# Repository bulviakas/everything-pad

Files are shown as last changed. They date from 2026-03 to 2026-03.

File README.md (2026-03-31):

# Everything pad - Custom macropad
A macropad project for the __Blueprint program__ by [Hack Club](https://hackclub.com/). 

The mini-keyboard features: 
  * 6 programmable keys
  * Rotary encoder
  * 8 RGB LEDs for backlight
  * OLED display

Designed to be a helpful tool while editing, gaming or just deep in flow state. ***The main goal - versatility***: multiple modes for every needed occasion (system sound control, application shortcuts, backlight configuration).

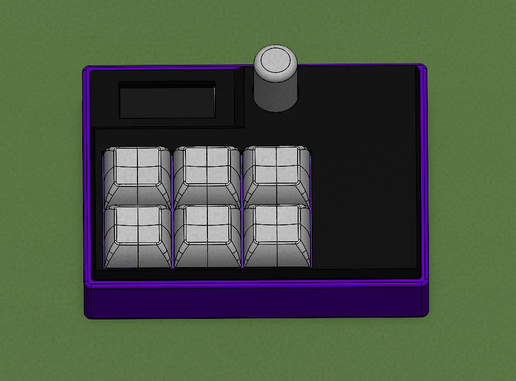
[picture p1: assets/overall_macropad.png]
Latest full version of the Everything pad


### Tools

* **PCB**: Custom-designed using **KiCad**
* **Case**: Modeled in **SolidWorks**
* **Firmware**: Built with **QMK**, supporting multiple layers, RGB lighting, encoder input, and OLED display

### Status
(2026-03-31) Project still in progress - no physical testing yet!

## PCB
### Schematic view

The keys and the rotary encoder are connected in a matrix.

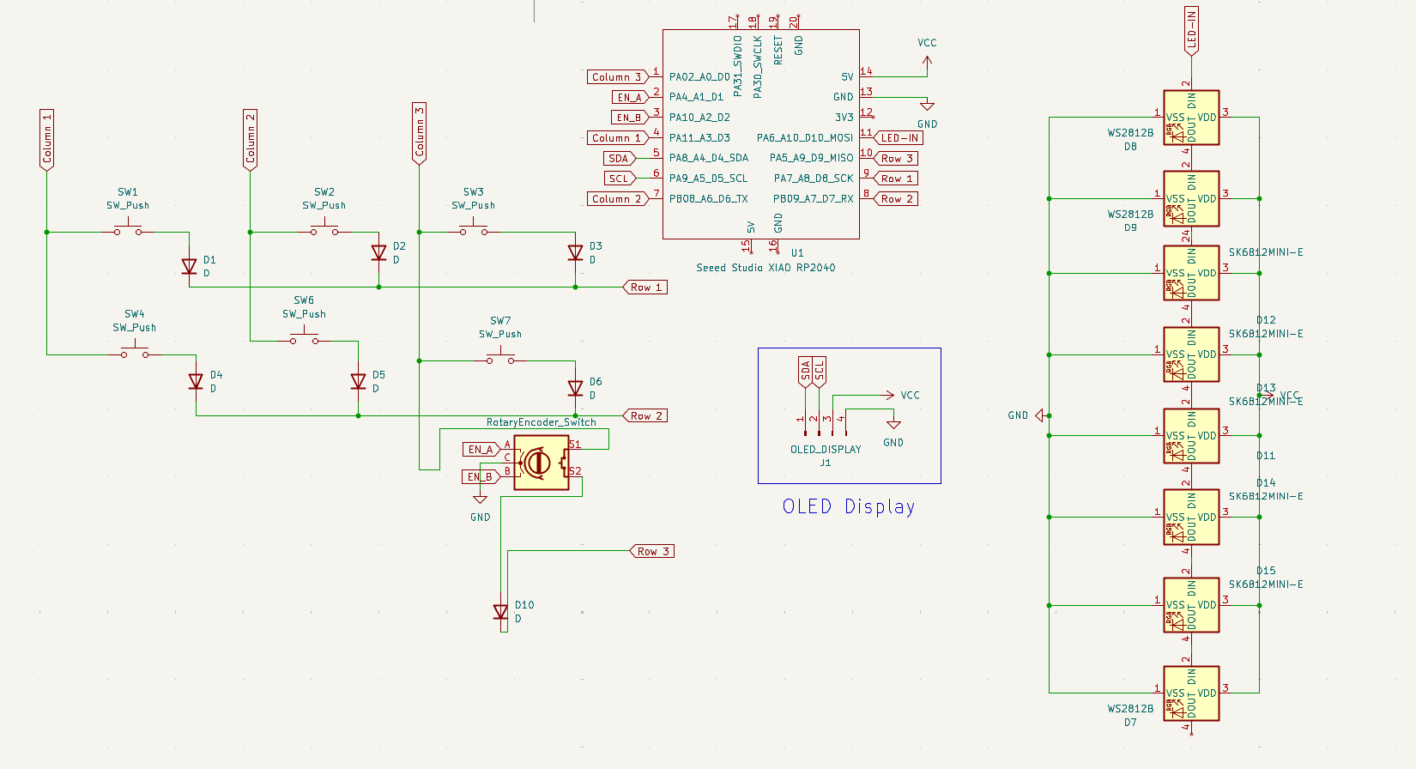
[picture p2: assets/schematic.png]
Scematic view of the Everything Pad


### The product itself

A personal character Steve was made with **Inkscape**. Everyting is connected over 2 layers, with 0.4mm traces and GND fields. SK6812-MINI-E LED footprints were modified due to clearance errors.

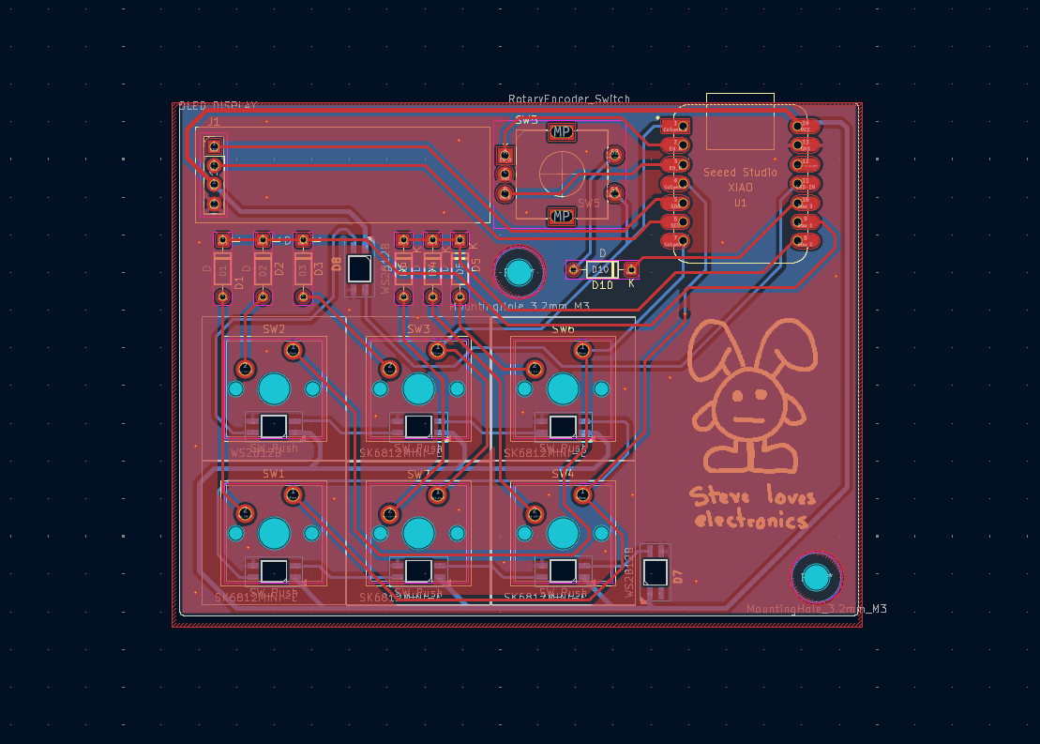
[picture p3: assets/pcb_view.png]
PCB view of the project


## CAD model

The assembly process is quite simple - the PCB is mounted onto the bottom part of the case with 2 M3 bolts and heatset inserts. Top cover just slides in from the top.

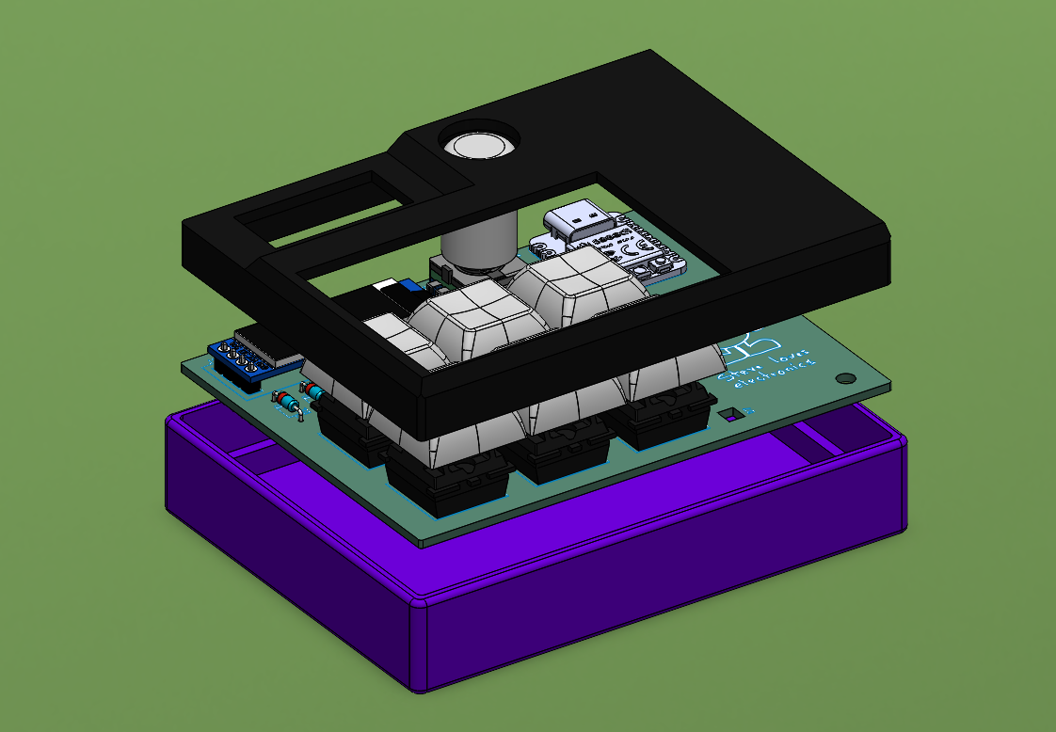
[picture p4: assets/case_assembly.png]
Assembly view of the case


## Firmware

As of now, the code is purely theoretical, since there is no way to test it. However, _in theory_, the keyboard has 3 modes:
* **System sound control** - play/pause music, increase/decrease volume, mute, etc.
* **Application shortcuts** - case-specific keybinds, eg. Discord toggle mute, toggle camera
* **RBG backlight configuration** - increase/decrease brightness, hue, etc.

The colour of the RBG backlight shows the currently active mode (SSC - Blue, Apps - Green, etc.). OLED display serves as the main info output when switching modes. Since the macropad cannot read real system sound values, it stores simulated volume and displays a simple bar on-screen when relevant.

## BOM
 A list of everything used to make this masterpiece:
 * 1x Seeed XIAO RP2040
 * 7x through-hole 1N4148 Diodes
 * 6x MX-Style switches
 * 1x EC11 Rotary encoder
 * 1x 0.91 inch OLED display (GND-VCC-SCL-SDA)
 * 6x white blank DSA keycaps
 * 8x SK6812 MINI-E LEDs
 * 2x M3x16mm screws
 * 2x M3x5mx4mm heatset inserts
 * 1x case (2 printed parts)
 * 1x printed knob for the encoder
 * Some joy and whimsy~

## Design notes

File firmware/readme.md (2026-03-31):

# everything_pad

*A short description of the keyboard/project*

* Keyboard Maintainer: [Akvilė Mačiulytė](https://github.com/bulviakas)
* Hardware Supported: Seeed XIAO RP2040
* Hardware Availability: -

Make example for this keyboard (after setting up your build environment):

    make everything_pad:default

Flashing example for this keyboard:

    make everything_pad:default:flash

See the [build environment setup](https://docs.qmk.fm/#/getting_started_build_tools) and the [make instructions](https://docs.qmk.fm/#/getting_started_make_guide) for more information. Brand new to QMK? Start with our [Complete Newbs Guide](https://docs.qmk.fm/#/newbs).

## Bootloader

Enter the bootloader in 3 ways:

* **Bootmagic reset**: Hold down the key at (0,0) in the matrix (usually the top left key or Escape) and plug in the keyboard
* **Physical reset button**: Briefly press the button on the back of the PCB - some may have pads you must short instead
* **Keycode in layout**: Press the key mapped to `QK_BOOT` if it is available

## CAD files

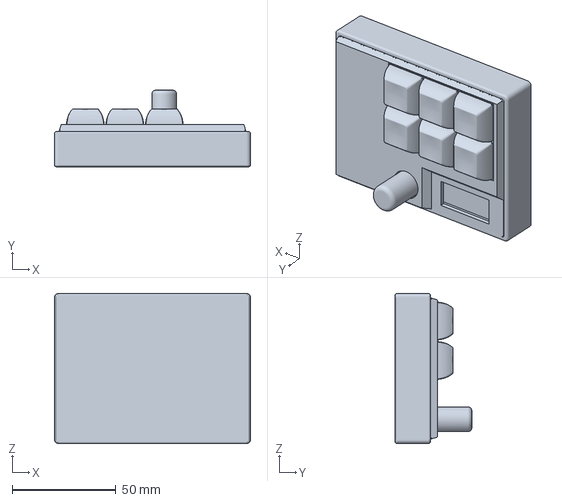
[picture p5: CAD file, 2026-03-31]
cad/everything_pad_assembly.3MF
94.5 x 37.0 x 72.5 mm

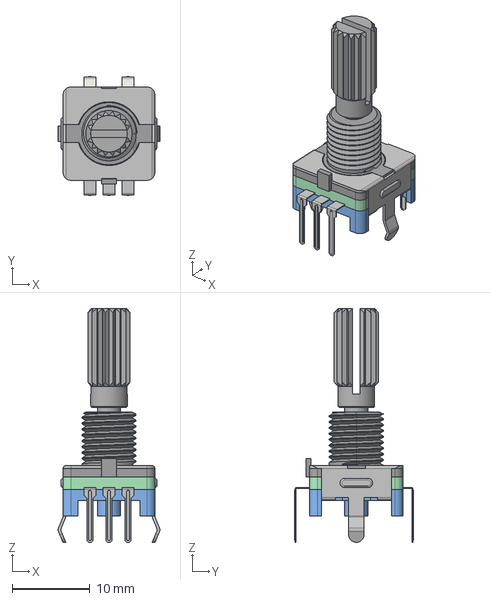
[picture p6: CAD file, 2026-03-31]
pcb/3d-models/EC11_Rotary_Encoder_Switched.step
13.1 x 15.3 x 30.1 mm

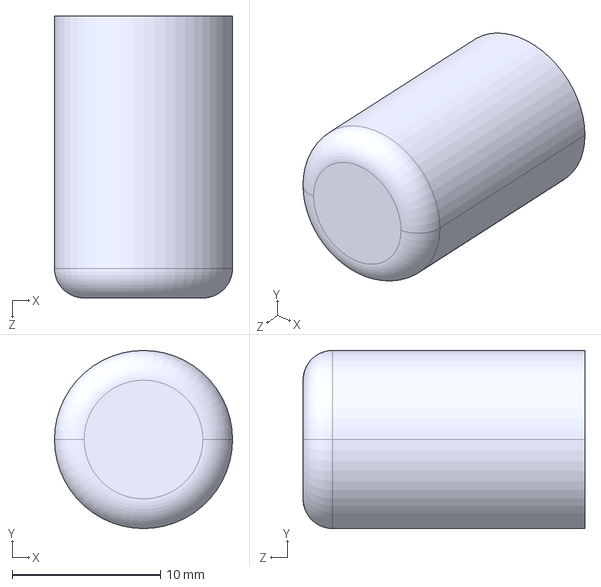
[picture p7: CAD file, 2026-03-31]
production/knob.STEP
12.0 x 12.0 x 19.0 mm

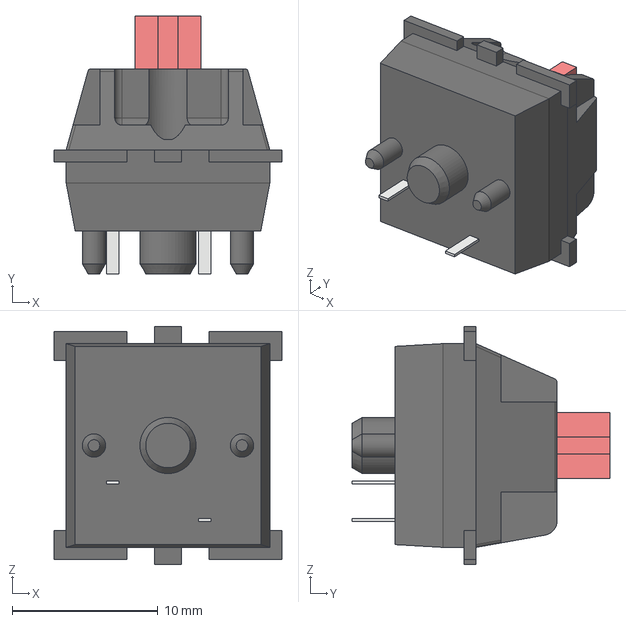
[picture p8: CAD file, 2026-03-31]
pcb/3d-models/switch.step
15.6 x 17.7 x 16.3 mm

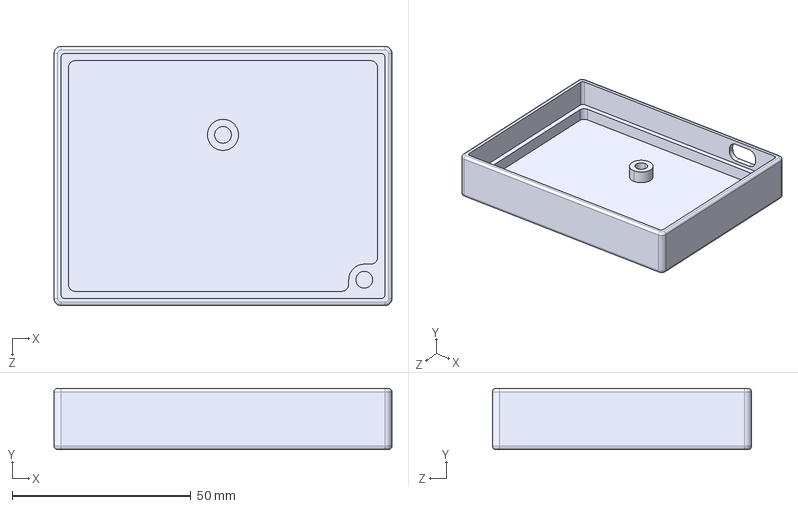
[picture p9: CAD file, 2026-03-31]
production/bottom.STEP
94.5 x 17.1 x 72.5 mm

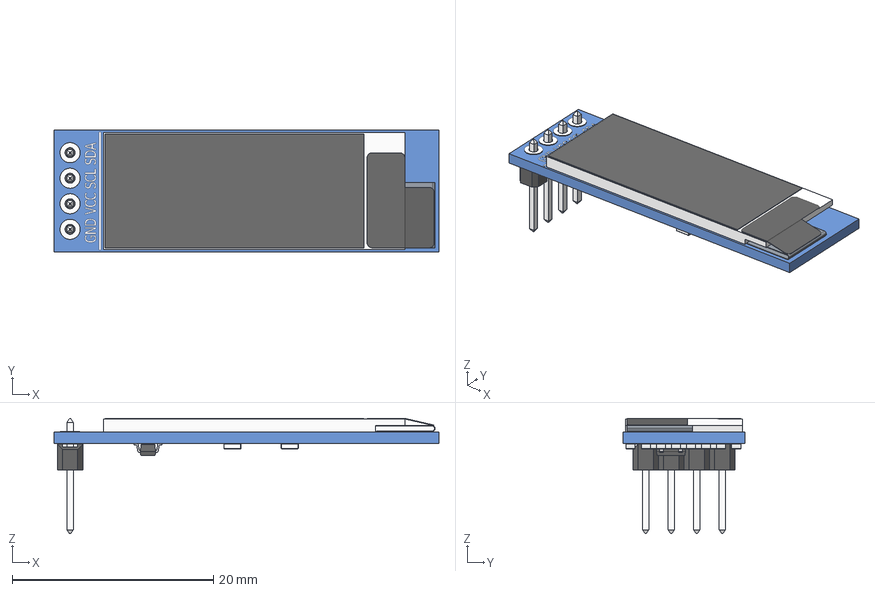
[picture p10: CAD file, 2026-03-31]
pcb/3d-models/OLED_0.91_128x32.stp
38.3 x 12.1 x 11.5 mm
OLED_0.91_128x32
Pin Header 4 x 1 TH 2.54mm Pitch
RESC-0603 x 13
2SD0601A

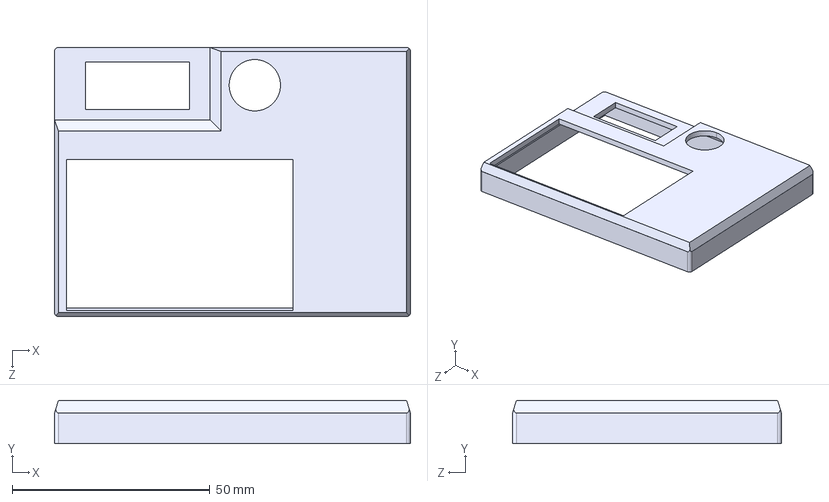
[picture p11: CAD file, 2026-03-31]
production/top.STEP
90.1 x 11.0 x 68.1 mm

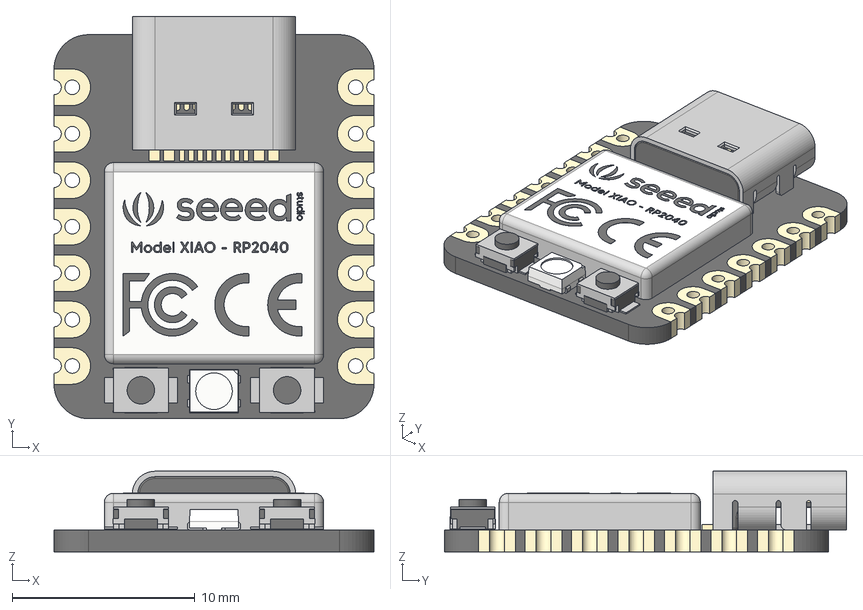
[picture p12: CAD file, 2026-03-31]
pcb/3d-models/Seeed Studio XIAO RP2040 v26.step
17.5 x 22.0 x 4.40 mm
type-c v2
smd_button v3
DOUT
DIN
VSS
VDD
smd_button v3(Mirror)

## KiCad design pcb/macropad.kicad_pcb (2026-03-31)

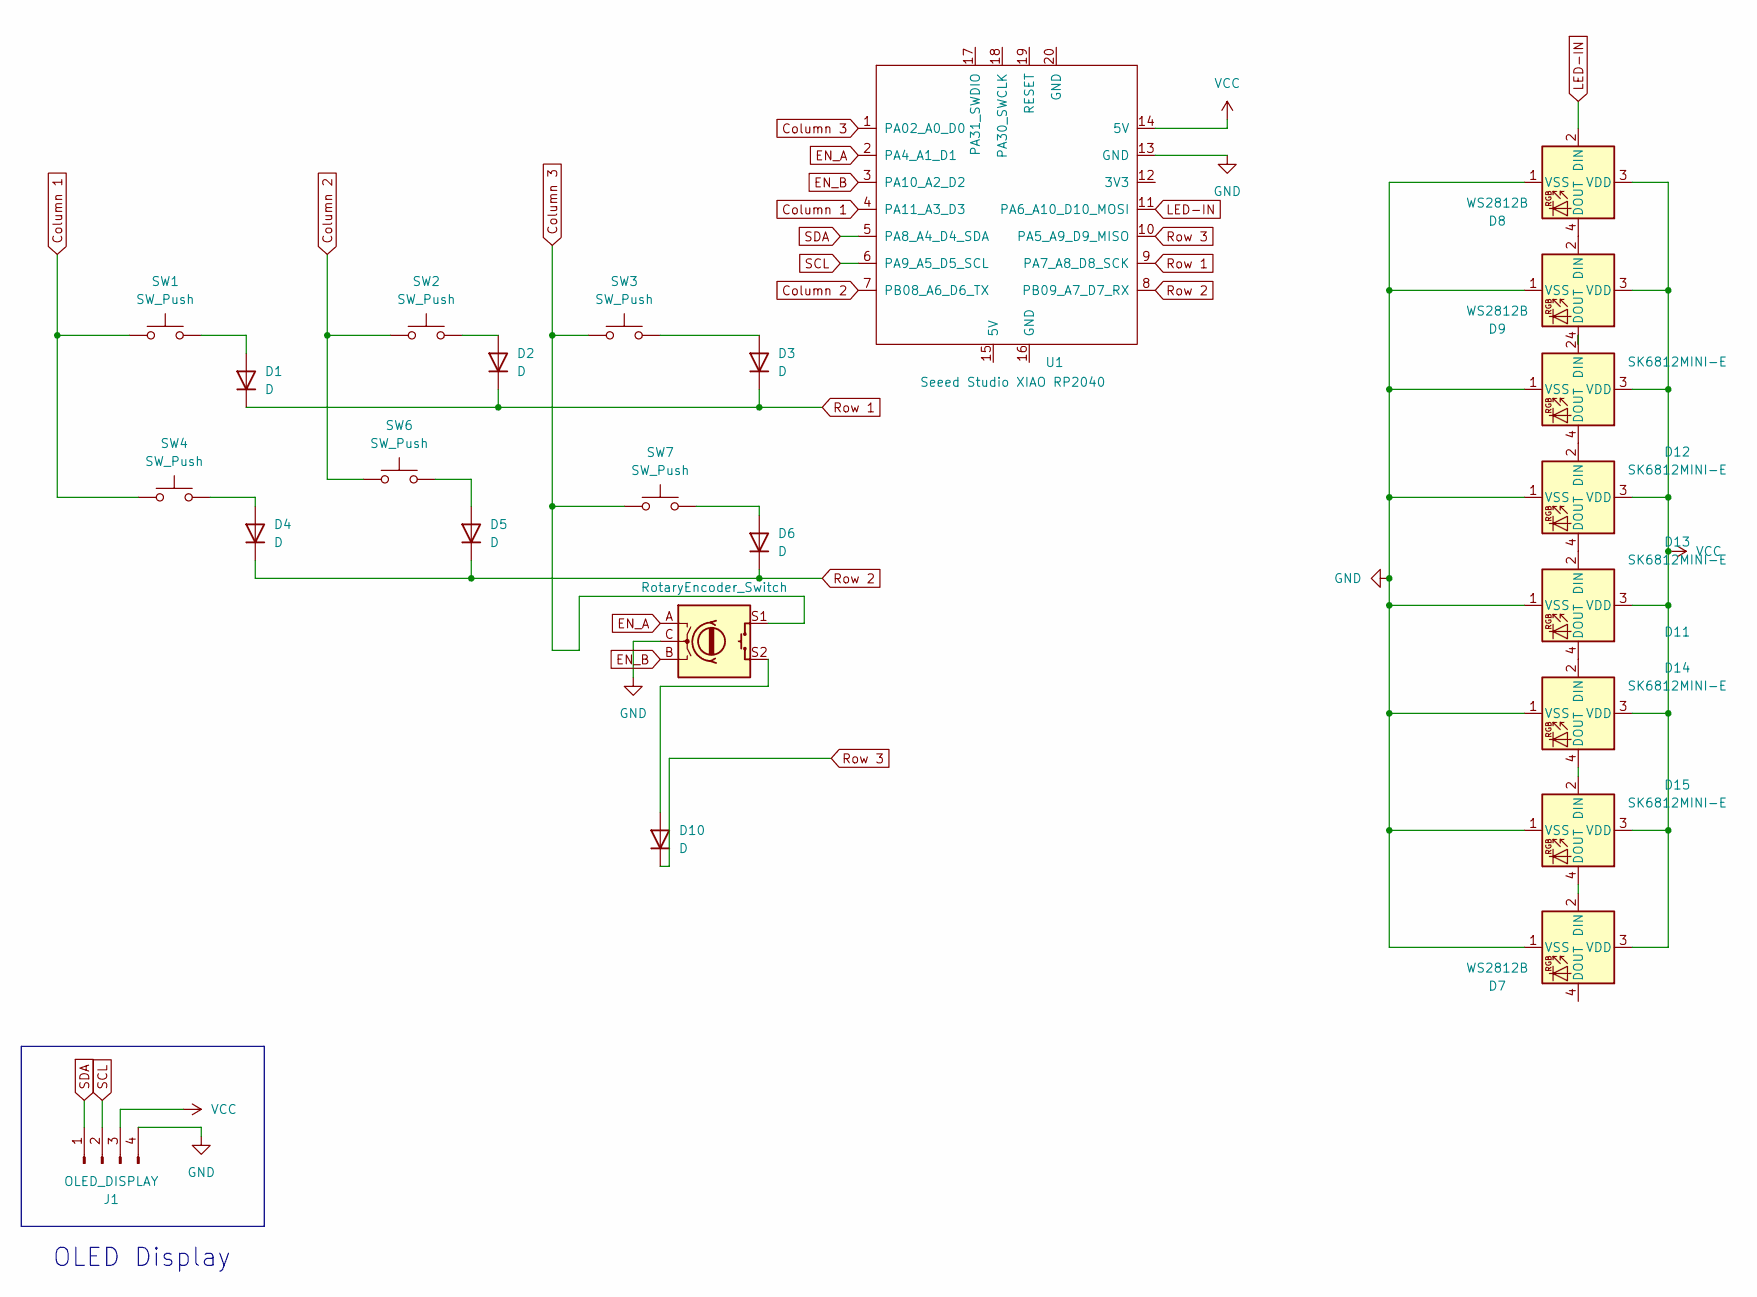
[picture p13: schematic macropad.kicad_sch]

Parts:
D1, D2, D3, D4, D5, D6, D10: D; D_DO-35_SOD27_P7.62mm_Horizontal
D7, D8: WS2812B; SK6812MINI-E_fixed
D9: WS2812B; MX_SK6812MINI-E
D11, D12, D13, D14, D15: SK6812MINI-E; MX_SK6812MINI-E
J1: OLED_DISPLAY; PinHeader_1x04_P2.54mm_Vertical
SW1, SW2, SW3, SW4, SW6, SW7: SW_Push; SW_Cherry_MX_1.00u_PCB
SW5: RotaryEncoder_Switch; RotaryEncoder_Alps_EC11E-Switch_Vertical_H20mm
U1: Seeed Studio XIAO RP2040; XIAO-Generic-Hybrid-14P-2.54-21X17.8MM

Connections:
Column 1: SW1.1, SW4.1, U1.4 (PA11_A3_D3)
Column 2: SW2.1, SW6.1, U1.7 (PB08_A6_D6_TX)
Column 3: SW3.1, SW5.S1, SW7.1, U1.1 (PA02_A0_D0)
EN_A: SW5.A, U1.2 (PA4_A1_D1)
EN_B: SW5.B, U1.3 (PA10_A2_D2)
GND: D7.1 (VSS), D8.1 (VSS), D9.1 (VSS), D11.1 (VSS), D12.1 (VSS), D13.1 (VSS), D14.1 (VSS), D15.1 (VSS), J1.4, SW5.C, U1.13 (GND)
LED-IN: D8.2 (DIN), U1.11 (PA6_A10_D10_MOSI)
unnamed: D1.2 (A), SW1.2
unnamed: D2.2 (A), SW2.2
unnamed: D3.2 (A), SW3.2
unnamed: D4.2 (A), SW4.2
unnamed: D5.2 (A), SW6.2
unnamed: D6.2 (A), SW7.2
unnamed: D8.4 (DOUT), D9.2 (DIN)
unnamed: D10.2 (A), SW5.S2
unnamed: D9.4 (DOUT), D11.2 (DIN)
unnamed: D11.4 (DOUT), D12.2 (DIN)
unnamed: D12.4 (DOUT), D13.2 (DIN)
unnamed: D13.4 (DOUT), D14.2 (DIN)
unnamed: D14.4 (DOUT), D15.2 (DIN)
unnamed: D7.2 (DIN), D15.4 (DOUT)
Row 1: D1.1 (K), D2.1 (K), D3.1 (K), U1.9 (PA7_A8_D8_SCK)
Row 2: D4.1 (K), D5.1 (K), D6.1 (K), U1.8 (PB09_A7_D7_RX)
Row 3: D10.1 (K), U1.10 (PA5_A9_D9_MISO)
SCL: J1.2, U1.6 (PA9_A5_D5_SCL)
SDA: J1.1, U1.5 (PA8_A4_D4_SDA)
VCC: D7.3 (VDD), D8.3 (VDD), D9.3 (VDD), D11.3 (VDD), D12.3 (VDD), D13.3 (VDD), D14.3 (VDD), D15.3 (VDD), J1.3, U1.14 (5V)

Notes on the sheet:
OLED Display

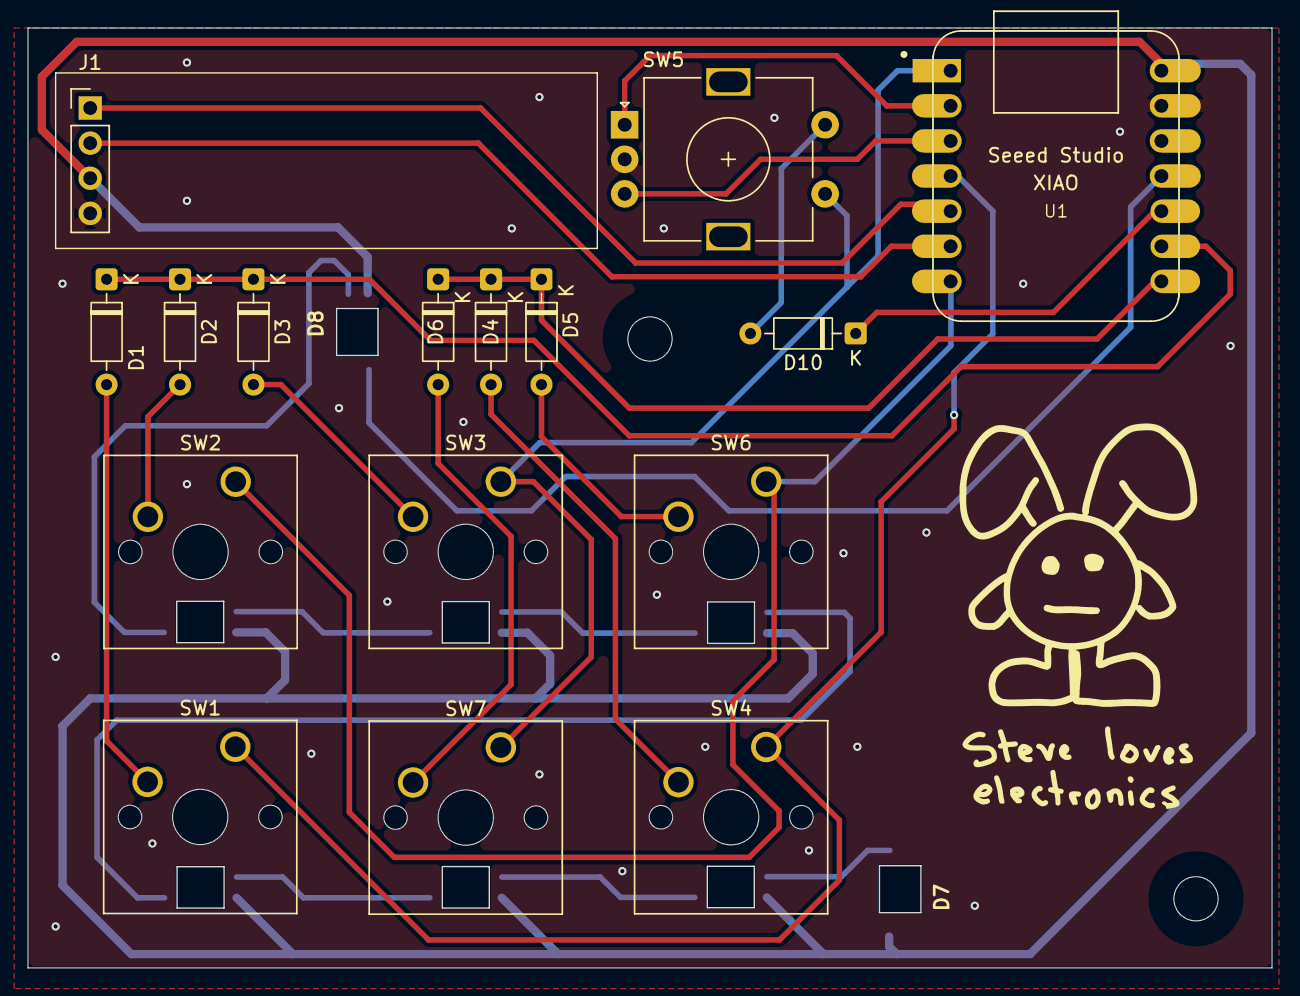
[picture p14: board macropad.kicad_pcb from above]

Board: 2 copper layers, 90.0 x 68.0 mm, 24 parts (0 on the bottom side), 27 nets.

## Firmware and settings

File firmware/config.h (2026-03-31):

#pragma once

#define ENCODER_A_PINS { GP27 }
#define ENCODER_B_PINS { GP28 }

#define WS2812_DI_PIN GP3
#define RGBLIGHT_LED_COUNT 8

#define RGBLIGHT_EFFECTS

#define RGBLIGHT_LIMIT_VAL 120
#define RGBLIGHT_SLEEP

#define OLED_DRIVER_ENABLE

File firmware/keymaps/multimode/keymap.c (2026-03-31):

// Copyright 2023 QMK
// SPDX-License-Identifier: GPL-2.0-or-later
#ifndef QK_RGBLIGHT_TOGGLE
#define QK_RGBLIGHT_TOGGLE        0x0A90
#define QK_RGBLIGHT_MODE_NEXT      0x0A91
#define QK_RGBLIGHT_INCREASE_VAL   0x0A92
#define QK_RGBLIGHT_DECREASE_VAL   0x0A93
#define QK_RGBLIGHT_INCREASE_HUE   0x0A94
#define QK_RGBLIGHT_INCREASE_SAT   0x0A95
#endif

#define RGB_TOG QK_RGBLIGHT_TOGGLE
#define RGB_MOD QK_RGBLIGHT_MODE_NEXT
#define RGB_VAI QK_RGBLIGHT_INCREASE_VAL
#define RGB_VAD QK_RGBLIGHT_DECREASE_VAL
#define RGB_HUI QK_RGBLIGHT_INCREASE_HUE
#define RGB_SAI QK_RGBLIGHT_INCREASE_SAT

#include QMK_KEYBOARD_H
#include "rgblight.h"

// Layers - modes
enum layers {
    _MEDIA,   // Default - system sound control
    _APP,     // App-specific shortcuts
    _RGB,     // RGB control
};

#if defined(ENCODER_MAP_ENABLE)
const uint16_t PROGMEM encoder_map[][NUM_ENCODERS][NUM_DIRECTIONS] = {
    [_MEDIA] = { ENCODER_CCW_CW(KC_VOLD, KC_VOLU) },  // Volume down/up
    [_APP]   = { ENCODER_CCW_CW(KC_MPRV, KC_MNXT) },  // Prev/Next track
    [_RGB]   = { ENCODER_CCW_CW(RGB_VAD, RGB_VAI) },  // RGB brightness
};
#endif

// Keymaps 
const uint16_t PROGMEM keymaps[][MATRIX_ROWS][MATRIX_COLS] = {

    [_MEDIA] = LAYOUT(
        KC_MPLY,   KC_MSTP,             // Play/Pause,  Stop
        KC_MUTE,   MO(_APP),            // Mute, Hold -> App mode
        KC_VOLD,   KC_VOLU,   KC_MSEL  // Vol-, Vol+, Open media player
    ),

    [_APP] = LAYOUT(
        LCTL(LSFT(KC_M)),   LCTL(LSFT(KC_K)),    // Discord: Mute, Toggle Camera (Custom keybind Ctrl + Shift + K)
        KC_TRNS,   KC_TRNS,
        KC_TRNS,   KC_TRNS,   MO(_RGB) // Hold -> RGB mode
    ),

    [_RGB] = LAYOUT(
        RGB_TOG,   RGB_MOD,
        RGB_HUI,   KC_TRNS,
        RGB_SAI,   RGB_VAI,   KC_TRNS
    ),
};

// RGB mode color indicators
layer_state_t layer_state_set_user(layer_state_t state) {
    switch (get_highest_layer(state)) {
        case _MEDIA:
            rgblight_setrgb(0, 100, 255);   // Blue for sound control
            break;
        case _APP:
            rgblight_setrgb(0, 255, 100);   // Green for apps
            break;
        case _RGB:
            rgblight_setrgb(255, 100, 0);   // Orange for LED control
            break;
    }
    return state;
}

// OLED display
#ifdef OLED_ENABLE

static void render_layer_status(void) {
    oled_write_P(PSTR("LAYER: "), false);
    switch (get_highest_layer(layer_state)) {
        case _MEDIA:
            oled_write_ln_P(PSTR("MEDIA"), false);
            break;
        case _APP:
            oled_write_ln_P(PSTR("APP  "), false);
            break;
        case _RGB:
            oled_write_ln_P(PSTR("RGB  "), false);
            break;
        default:
            oled_write_ln_P(PSTR("CRAZY SHOT BRO"), false);
    }
}

static void render_volume_bar(uint8_t vol) {
    oled_write_P(PSTR("VOL: "), false);
    // Simple ASCII bar (0–15 blocks)
    uint8_t filled = vol / 8;
    for (uint8_t i = 0; i < 16; i++) {
        oled_write_char(i < filled ? '#' : '-', false);
    }
    oled_write_ln_P(PSTR(""), false);
}

// Track simulated volume (because the pad can't know the real value)
static uint8_t sim_volume = 64;  // 0–127

bool process_record_user(uint16_t keycode, keyrecord_t *record) {
    if (record->event.pressed) {
        switch (keycode) {
            case KC_VOLU:
                if (sim_volume < 120) sim_volume += 8;
                break;
            case KC_VOLD:
                if (sim_volume > 7)   sim_volume -= 8;
                break;
            case KC_MUTE:
                sim_volume = (sim_volume > 0) ? 0 : 64;
                break;
        }
    }
    return true;
}

bool oled_task_user(void) {
    oled_write_ln_P(PSTR("  SOUND CENTER  "), true);  // inverted header
    oled_write_ln_P(PSTR(""), false);
    render_layer_status();
    oled_write_ln_P(PSTR(""), false);
    render_volume_bar(sim_volume);
    oled_write_ln_P(PSTR("ENC: Vol / Track"), false);
    return false;
}

#endif // OLED_ENABLE

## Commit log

2026-03-25 Created the PCB with all needed basic functionalities
    [macropad.kicad_pcb, macropad.kicad_sch]
2026-03-26 V1.2 - Fixed the LED symbols and retraced everything
    [macropad.kicad_pcb, macropad.kicad_sch]
2026-03-27 V1.3 - Added switch LEDs and GND fields
    [macropad.kicad_pcb, macropad.kicad_sch]
2026-03-27 .gitignore update
    [macropad.kicad_pcb]
2026-03-27 Imported graphics for the PCB
2026-03-27 V1.4 - Reworked GND fields, solved all errors, added Steve
    [macropad.kicad_pcb]
2026-03-31 Moved the KiCad libraries. Added the CAD case elements
    [EC11_Rotary_Encoder_Switched.step, OLED_0.91_128x32.stp, Seeed Studio XIAO RP2040 v26.step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]
2026-03-31 Added case production STEP files
    [bottom.STEP, knob.STEP, top.STEP]
2026-03-31 V1.5 - Fixed faulty encoder wiring, retraced
    [macropad.kicad_pcb, macropad.kicad_sch]
2026-03-31 Updated README.md BOM
2026-03-31 Added PCB Gerber files
